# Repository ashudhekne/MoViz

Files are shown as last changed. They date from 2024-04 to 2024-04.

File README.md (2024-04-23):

# MoViz
Motion visualization using UWB and IMU

#HardwareFiles
If you want to manufacture your own UWB+IMU+SDCard+Cortex M0 devices, you can start from the harware files.
This is the hardware we used for our experiments. 

#FirmwareFiles
These files are loaded on the hardware. They are Arduino based.

#VisualizationFiles
These files contain the Processing.org files

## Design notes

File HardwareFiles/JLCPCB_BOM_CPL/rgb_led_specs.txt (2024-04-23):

First Ring design:
WS2812B-MINI-X1
C4154873

Previous UWB Watch system:
XINGLIGHT XL-3535RGBC-WS2812B

C2843786

Current BOM:
XINGLIGHT XL-3535RGBC-WS2812B
C2843786

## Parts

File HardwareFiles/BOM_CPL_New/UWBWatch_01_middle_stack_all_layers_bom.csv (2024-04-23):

Comment | Designator | Footprint | LCSC Part #
microsd | X4 | MICROSD | C2889263

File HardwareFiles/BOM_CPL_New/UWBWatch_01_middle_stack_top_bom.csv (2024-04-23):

Comment | Designator | Footprint | LCSC Part #
microsd | X4 | MICROSD

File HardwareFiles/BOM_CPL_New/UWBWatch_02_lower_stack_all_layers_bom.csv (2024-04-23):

Comment | Designator | Footprint | LCSC Part #
0.1uF | C3 C16 C17 C19 | 0402
1.0uF | C18 | 0603
1K | R6 | 0603-NO
2.2K | R9 | 0603-NO
4.7k | R1 | 0603
10k | R13 | 0603
10uF | C2 C11 C15 | 0805-NO
10µF | C10 | 0805-NO
100k | R4 | 0603-NO
10103594-0001LF | J1 | AMPHENOL_10103594-0001LF
B3U-3000P | S1 | SW_B3U-3000P
MBR120 | D4 | SOD-123
MCP73831T-2ACI/OT | U3 | SOT23-5
RED | L | CHIPLED_0805_NOOUTLINE
SPX3819-3.3 | U2 | SOT23-5
WS2812B3535 | LED1 | LED3535
0.1uF | C1 C4 | 0402
1uF | C5 C9 C14 | 0603-NO
4.7k | R2 | 0603
10K\ | R8 | 0603-NO
10uF | C13 | 0805-NO
10µF | C8 C12 | 0805-NO
22pF | C6 C7 | 0603-NO
32.768 | X2 | XTAL3215
100K | R5 | 0603-NO
100k | R3 | 0603-NO
ATSAMD21G18_QFN | U$4 | TQFN48_7MM
LIS2MDL | IC1 | LGA12_2X2MM
LSM6DS0 | U1 | LGA14L

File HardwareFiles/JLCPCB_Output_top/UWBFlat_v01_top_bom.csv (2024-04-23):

Comment | Designator | Footprint | LCSC Part #
0.1uF | C3 C16 C17 C19 | 0402
1.0uF | C18 | 0603
1K | R6 | 0603-NO
2.2K | R9 | 0603-NO
4.7k | R1 | 0603
10k | R13 | 0603
10uF | C2 C11 C15 | 0805-NO
10µF | C10 | 0805-NO
22uF | C20 C21 C22 | 0805
100k | R4 | 0603-NO
100k | R7 | 0603
10103594-0001LF | J1 | AMPHENOL_10103594-0001LF
B3U-3000P | S1 | SW_B3U-3000P
DWM1000 | U$1 | DWM1000
MBR120 | D4 | SOD-123
MCP73831T-2ACI/OT | U3 | SOT23-5
RED | L | CHIPLED_0805_NOOUTLINE
SPX3819-3.3 | U2 | SOT23-5
WS2812B3535 | LED1 | LED3535

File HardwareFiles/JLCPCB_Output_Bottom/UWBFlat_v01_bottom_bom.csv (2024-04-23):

Comment | Designator | Footprint | LCSC Part #
0.1uF | C1 C4 | 0402
1uF | C5 C9 C14 | 0603-NO
4.7k | R2 | 0603
10K\ | R8 | 0603-NO
10uF | C13 | 0805-NO
10µF | C8 C12 | 0805-NO
22pF | C6 C7 | 0603-NO
32.768 | X2 | XTAL3215
100K | R5 | 0603-NO
100k | R3 | 0603-NO
10103594-0001LF | J1 | AMPHENOL_10103594-0001LF
ATSAMD21G18_QFN | U$4 | TQFN48_7MM
LIS2MDL | IC1 | LGA12_2X2MM
LSM6DS0 | U1 | LGA14L
microsd | X4 | MICROSD

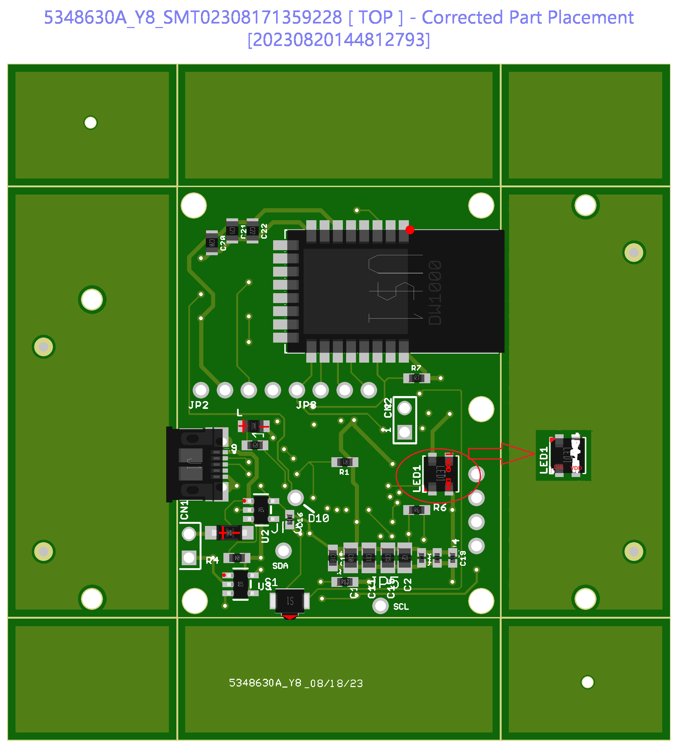
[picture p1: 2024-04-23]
HardwareFiles/JLCPCB_BOM_CPL/Produce_DanZhi.SMT_Snapshot.Top.5348630A_Y8.SMT02308171359228_corrected.png

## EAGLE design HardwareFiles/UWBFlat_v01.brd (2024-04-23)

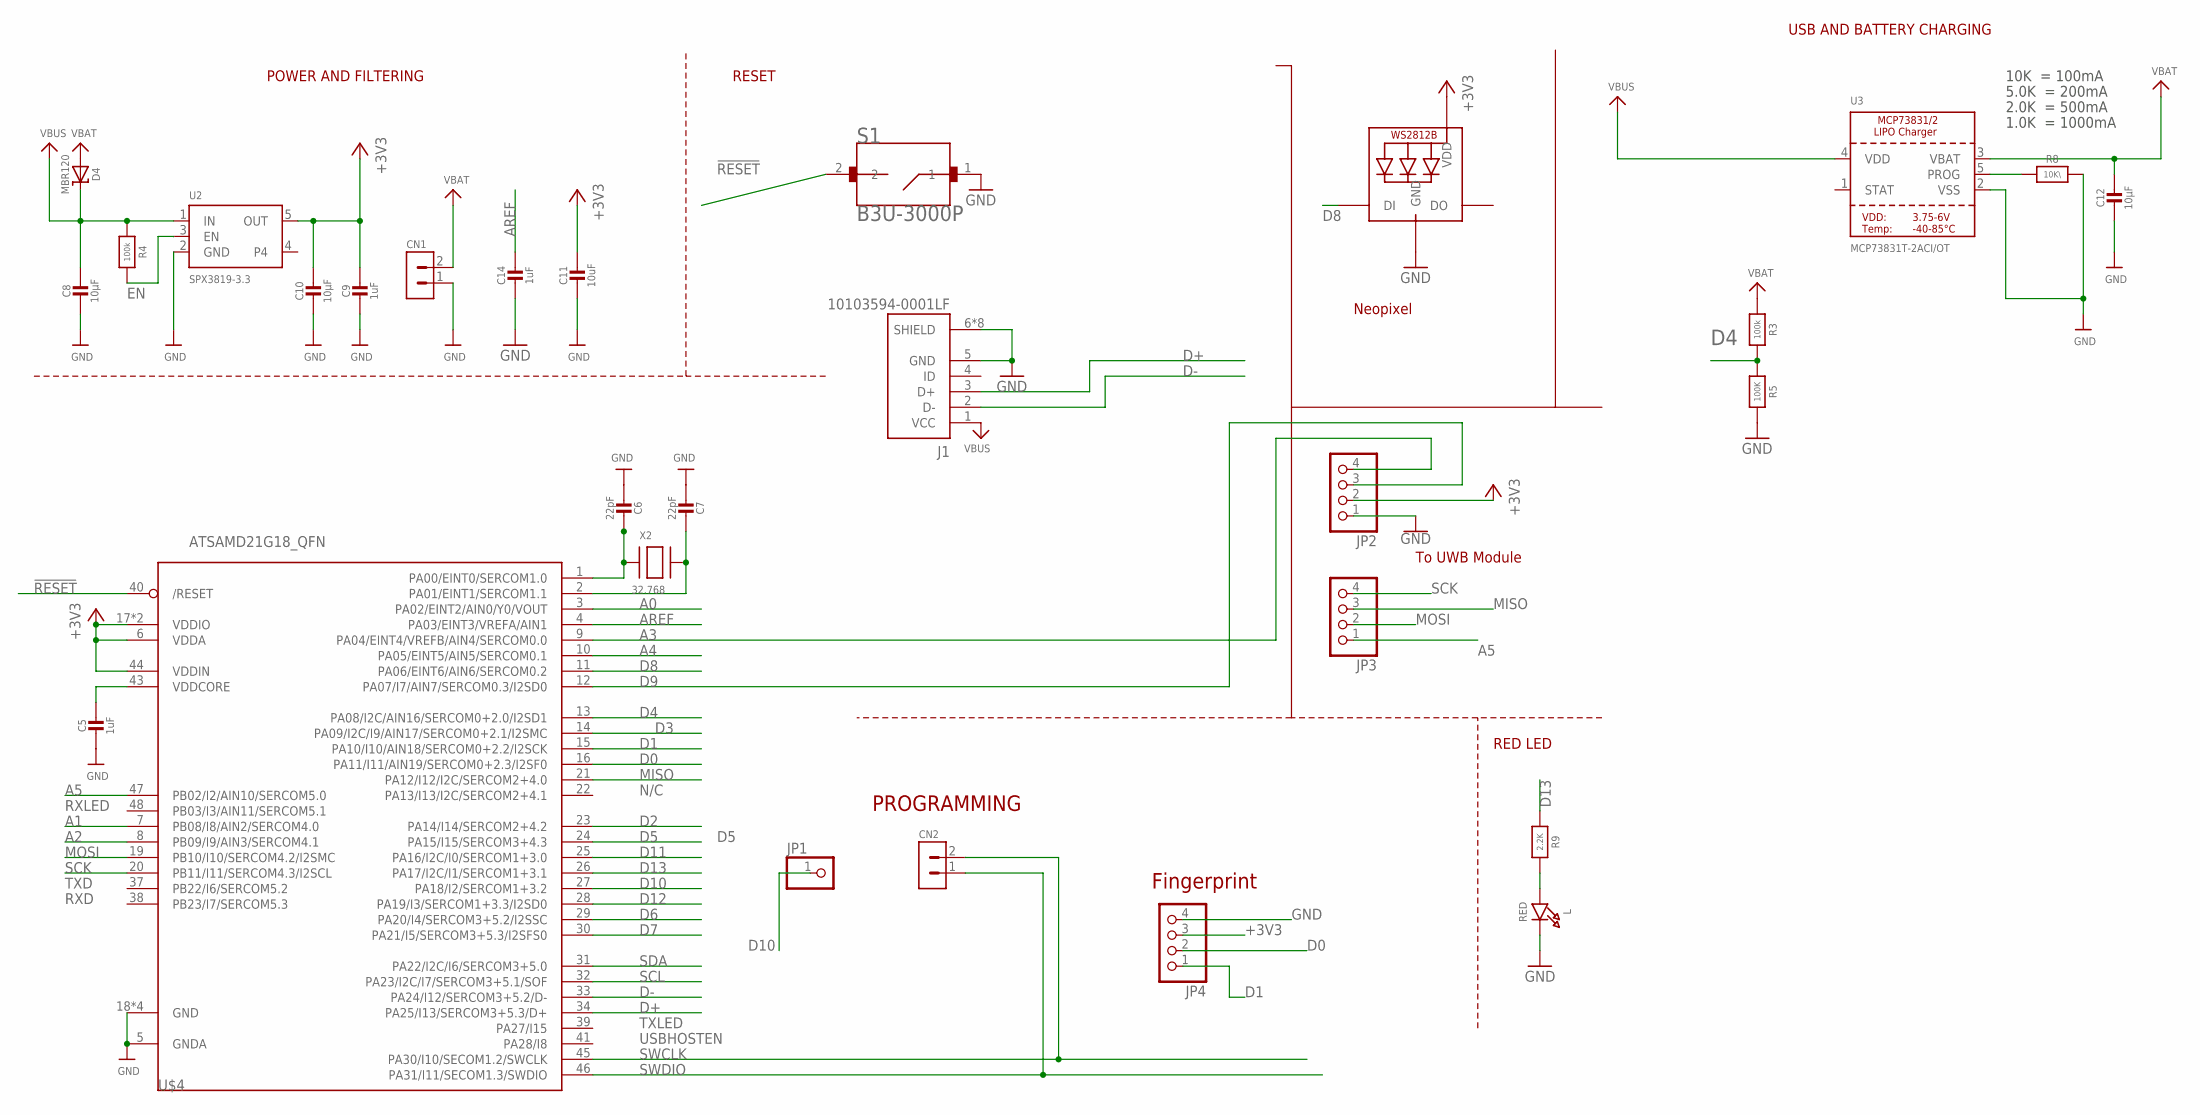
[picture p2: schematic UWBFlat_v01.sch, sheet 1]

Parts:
C5, C9, C14: 1uF; 0603-NO
C6, C7: 22pF; 0603-NO
C8, C10, C12: 10µF; 0805-NO
C11: 10uF; 0805-NO
CN1, CN2: HEADER_1X02
D4: MBR120; SOD-123
J1: 10103594-0001LF; AMPHENOL_10103594-0001LF
JP1: PINHD-1X1CB; 1X01-CLEANBIG
JP2, JP3, JP4: HEADER-1X4ROUND; 1X04_ROUND
L: RED; CHIPLED_0805_NOOUTLINE
LED1: WS2812B3535; LED3535
R3, R4: 100k; 0603-NO
R5: 100K; 0603-NO
R8: 10K\; 0603-NO
R9: 2.2K; 0603-NO
S1: B3U-3000P; SW_B3U-3000P
U2: SPX3819-3.3; SOT23-5
U3: MCP73831T-2ACI/OT; SOT23-5
U$4: ATSAMD21G18_QFN; TQFN48_7MM
X2: 32.768; XTAL3215

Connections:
!RESET: S1.2, U$4.40 (/RESET)
+3V3: C9.1, C10.1, C11.1, JP2.2, JP4.3, LED1.2 (VDD), U2.5 (OUT), U$4.6 (VDDA), U$4.17 (VDDIO), U$4.36 (VDDIO), U$4.44 (VDDIN); also elsewhere on the board
A0: U$4.3 (PA02/EINT2/AIN0/Y0/VOUT)
A1: U$4.7 (PB08/I8/AIN2/SERCOM4.0)
A2: U$4.8 (PB09/I9/AIN3/SERCOM4.1)
A3: JP2.4, U$4.9 (PA04/EINT4/VREFB/AIN4/SERCOM0.0); also elsewhere on the board
A4: U$4.10 (PA05/EINT5/AIN5/SERCOM0.1)
A5: JP3.1, U$4.47 (PB02/I2/AIN10/SERCOM5.0); also elsewhere on the board
AREF: C14.1, U$4.4 (PA03/EINT3/VREFA/AIN1)
D0: JP4.2, U$4.16 (PA11/I11/AIN19/SERCOM0+2.3/I2SF0)
D1: JP4.1, U$4.15 (PA10/I10/AIN18/SERCOM0+2.2/I2SCK)
D2: U$4.23 (PA14/I14/SERCOM2+4.2)
D3: U$4.14 (PA09/I2C/I9/AIN17/SERCOM0+2.1/I2SMC)
D4: R3.2, R5.1, U$4.13 (PA08/I2C/AIN16/SERCOM0+2.0/I2SD1)
D5: U$4.24 (PA15/I15/SERCOM3+4.3)
D6: U$4.29 (PA20/I4/SERCOM3+5.2/I2SSC)
D7: U$4.30 (PA21/I5/SERCOM3+5.3/I2SFS0)
D8: LED1.1 (DI), U$4.11 (PA06/EINT6/AIN6/SERCOM0.2)
D9: JP2.3, U$4.12 (PA07/I7/AIN7/SERCOM0.3/I2SD0); also elsewhere on the board
D10: JP1.1, U$4.27 (PA18/I2/SERCOM1+3.2); also elsewhere on the board
D11: U$4.25 (PA16/I2C/I0/SERCOM1+3.0)
D12: U$4.28 (PA19/I3/SERCOM1+3.3/I2SD0)
D13: R9.1, U$4.26 (PA17/I2C/I1/SERCOM1+3.1)
D+: J1.3 (D+), U$4.34 (PA25/I13/SERCOM3+5.3/D+)
D-: J1.2 (D-), U$4.33 (PA24/I12/SERCOM3+5.2/D-)
EN: R4.2, U2.3 (EN)
GND: C5.2, C6.2, C7.2, C8.2, C9.2, C10.2, C11.2, C12.2, C14.2, CN1.1, J1.5 (GND), J1.6 (SHIELD), J1.7 (SHIELD), J1.8 (SHIELD), J1.9 (SHIELD), J1.10 (SHIELD), J1.11 (SHIELD), J1.S1 (SHIELD), J1.S2 (SHIELD), JP2.1, JP4.4, L.C, LED1.4 (GND), R5.2, R8.2, S1.1, U2.2 (GND), U3.2 (VSS), U$4.5 (GNDA), U$4.18 (GND), U$4.35 (GND), U$4.42 (GND), U$4.THERMAL (GND); also elsewhere on the board
MISO: JP3.3, U$4.21 (PA12/I12/I2C/SERCOM2+4.0); also elsewhere on the board
MOSI: JP3.2, U$4.19 (PB10/I10/SERCOM4.2/I2SMC); also elsewhere on the board
unnamed: R8.1, U3.5 (PROG)
unnamed: C6.1, U$4.1 (PA00/EINT0/SERCOM1.0), X2.P$1
unnamed: C7.1, U$4.2 (PA01/EINT1/SERCOM1.1), X2.P$2
unnamed: L.A, R9.2
SCK: JP3.4, U$4.20 (PB11/I11/SERCOM4.3/I2SCL); also elsewhere on the board
SCL: U$4.32 (PA23/I2C/I7/SERCOM3+5.1/SOF); also elsewhere on the board
SDA: U$4.31 (PA22/I2C/I6/SERCOM3+5.0); also elsewhere on the board
SWCLK: CN2.2, U$4.45 (PA30/I10/SECOM1.2/SWCLK)
SWDIO: CN2.1, U$4.46 (PA31/I11/SECOM1.3/SWDIO)
VBAT: C12.1, CN1.2, D4.A, R3.1, U3.3 (VBAT)
VBUS: C8.1, D4.C, J1.1 (VCC), R4.1, U2.1 (IN), U3.4 (VDD)
VDDCORE1: C5.1, U$4.43 (VDDCORE)

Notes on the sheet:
N/C
TXLED
USBHOSTEN
RXLED
TXD
RXD
POWER AND FILTERING
RESET
RED LED
PROGRAMMING
To UWB Module
Neopixel
10K = 100mA
5.0K = 200mA
2.0K = 500mA
1.0K = 1000mA
USB AND BATTERY CHARGING
Fingerprint

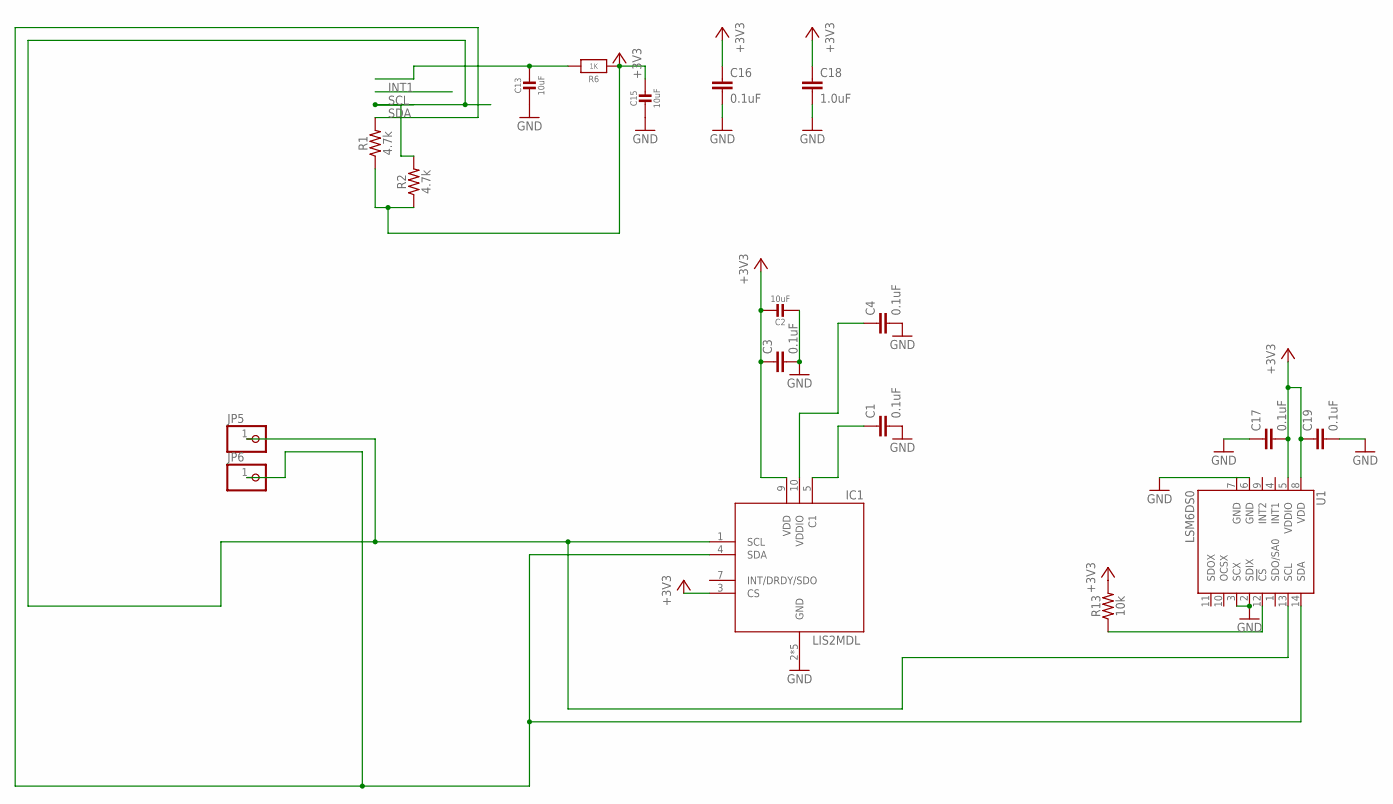
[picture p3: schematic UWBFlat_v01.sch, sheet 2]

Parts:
C1, C3, C4, C16, C17, C19: 0.1uF; 0402
C2, C13, C15: 10uF; 0805-NO
C18: 1.0uF; 0603
IC1: LIS2MDL; LGA12_2X2MM
JP5, JP6: PINHD-1X1CB; 1X01-CLEANBIG
R1, R2: 4.7k; 0603
R6: 1K; 0603-NO
R13: 10k; 0603
U1: LSM6DS0; LGA14L

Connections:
+3V3: C2.1, C3.1, C15.1, C16.1, C17.2, C18.1, C19.1, IC1.3 (CS), IC1.9 (VDD), R1.1, R2.1, R6.1, R13.2, U1.5 (VDDIO), U1.8 (VDD); also elsewhere on the board
GND: C1.2, C2.2, C3.2, C4.2, C13.2, C15.2, C16.2, C17.1, C18.2, C19.2, IC1.2 (GND), IC1.6 (GND), IC1.8 (GND), IC1.11 (GND), IC1.12 (GND), U1.2 (SDIX), U1.3 (SCX), U1.6 (GND), U1.7 (GND); also elsewhere on the board
unnamed: C13.1, R6.2
unnamed: C1.1, IC1.5 (C1)
unnamed: C4.1, IC1.10 (VDDIO)
unnamed: R13.1, U1.12 (!CS!)
SCL: IC1.1 (SCL), JP5.1, R2.2, U1.13 (SCL); also elsewhere on the board
SDA: IC1.4 (SDA), JP6.1, R1.2, U1.14 (SDA); also elsewhere on the board

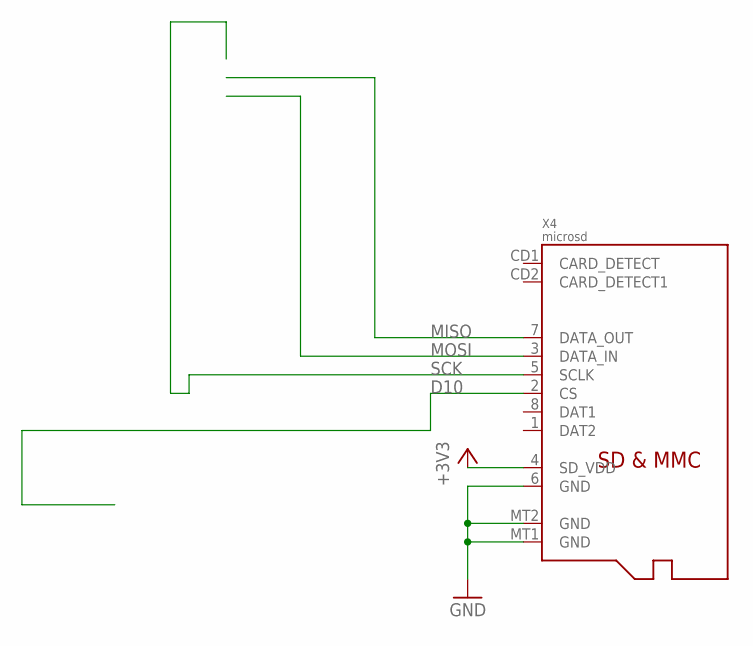
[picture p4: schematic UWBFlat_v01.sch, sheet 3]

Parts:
X4: microsd; MICROSD

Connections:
+3V3: X4.4 (SD_VDD); also elsewhere on the board
D10: X4.2 (CS); also elsewhere on the board
GND: X4.6 (GND), X4.MT1 (GND), X4.MT2 (GND); also elsewhere on the board
MISO: X4.7 (DATA_OUT); also elsewhere on the board
MOSI: X4.3 (DATA_IN); also elsewhere on the board
SCK: X4.5 (SCLK); also elsewhere on the board

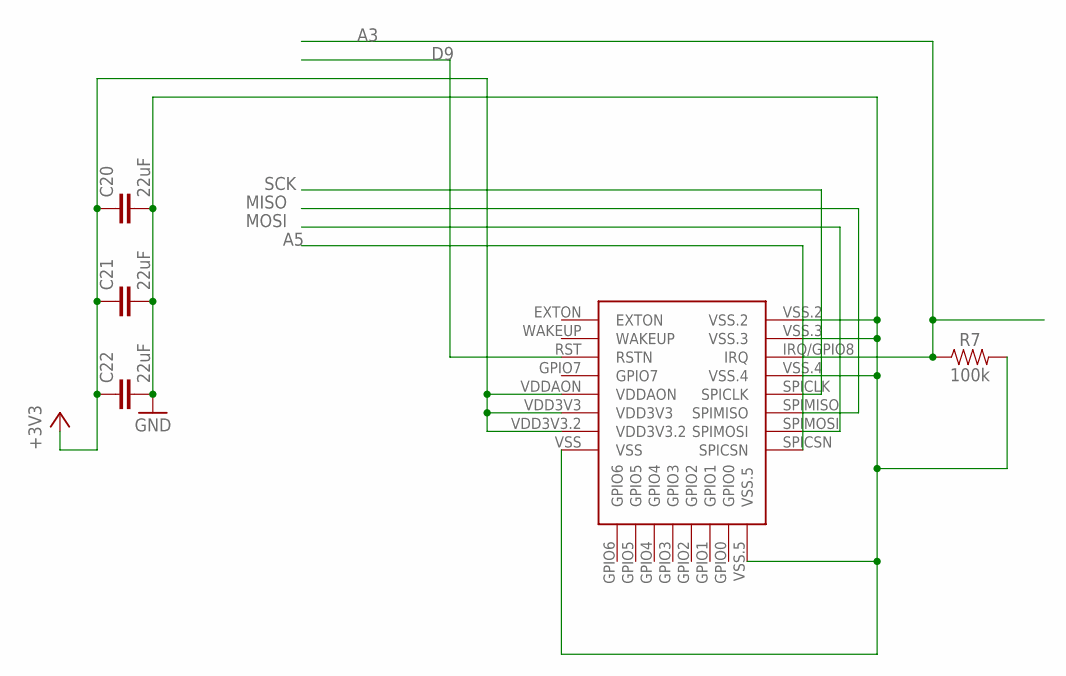
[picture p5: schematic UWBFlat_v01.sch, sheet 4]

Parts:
C20, C21, C22: 22uF; 0805
R7: 100k; 0603
U$1: DWM1000

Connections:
+3V3: C20.1, C21.1, C22.1, U$1.VDD3V3, U$1.VDD3V3.2, U$1.VDDAON; also elsewhere on the board
A3: R7.1, U$1.IRQ/GPIO8 (IRQ); also elsewhere on the board
A5: U$1.SPICSN; also elsewhere on the board
D9: U$1.RST (RSTN); also elsewhere on the board
GND: C20.2, C21.2, C22.2, R7.2, U$1.VSS, U$1.VSS.2, U$1.VSS.3, U$1.VSS.4, U$1.VSS.5; also elsewhere on the board
MISO: U$1.SPIMISO; also elsewhere on the board
MOSI: U$1.SPIMOSI; also elsewhere on the board
SCK: U$1.SPICLK; also elsewhere on the board

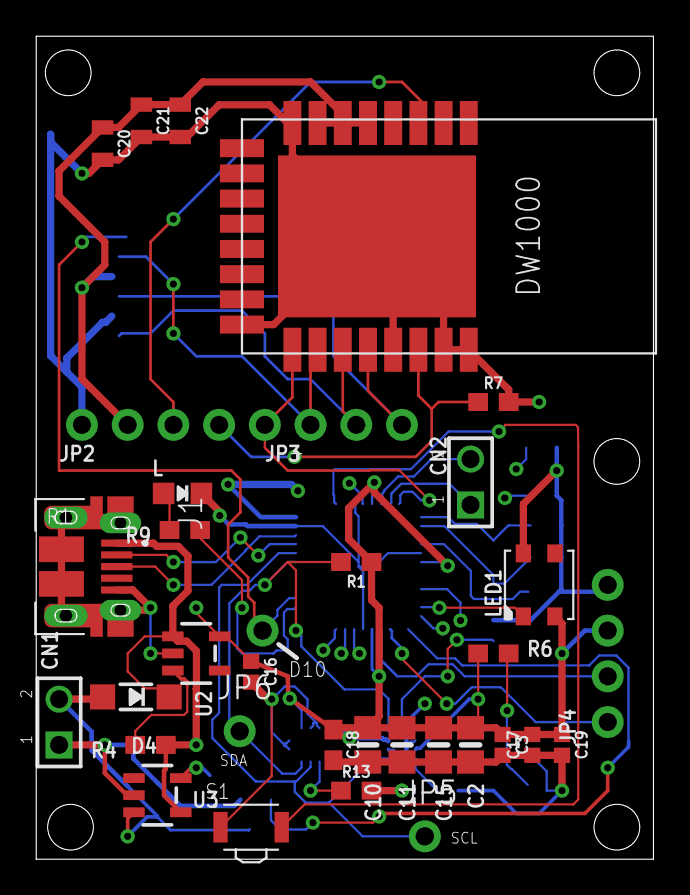
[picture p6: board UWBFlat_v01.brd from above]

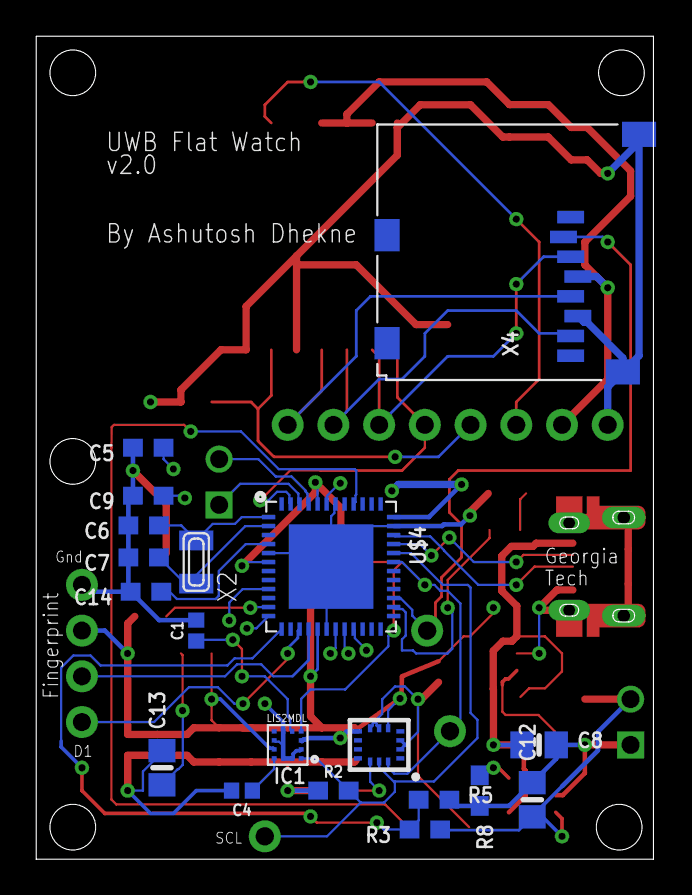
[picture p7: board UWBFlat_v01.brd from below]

Board: 4 copper layers, 34.3 x 45.7 mm, 53 parts (19 on the bottom side), 34 nets.

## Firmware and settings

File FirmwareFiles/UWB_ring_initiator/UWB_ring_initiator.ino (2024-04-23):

/*
 * Copyright (c) 2021 by Yifeng Cao <ycao361@gatech.edu>
 * Peer-peer protocol
 *
 * Licensed under the Apache License, Version 2.0 (the "License");
 * you may not use this file except in compliance with the License.
 * You may obtain a copy of the License at
 *
 *     http://www.apache.org/licenses/LICENSE-2.0
 *
 * Unless required by applicable law or agreed to in writing, software
 * distributed under the License is distributed on an "AS IS" BASIS,
 * WITHOUT WARRANTIES OR CONDITIONS OF ANY KIND, either express or implied.
 * See the License for the specific language governing permissions and
 * limitations under the License.
 *
 * @file DWM1000-TWR.ino
 * 
 *  
 */

#include <SPI.h>
#include <math.h>
#include <DW1000.h>
#include <DW1000Constants.h>
#include "ringActionFunctions.h"
#include "genericFunctions.h"
#include "RangingContainer.h"
#include "Adafruit_LSM9DS1.h"
#include <SdFat.h>
#include <time.h>
#include<TimeLib.h>
#include<Wire.h>
// #include <Adafruit_ISM330DHCX.h>
// #include <Adafruit_LIS3MDL.h>
#include <LSM6DSOSensor.h>

TwoWire dev_i2c(&sercom3, SDA, SCL);  
LSM6DSOSensor AccGyr(&dev_i2c);

// Adafruit_LIS3MDL lis3mdl;
// Adafruit_ISM330DHCX ism330dhcx;

// PIN Macro
#define VBATPIN A2
#define LED_PIN 12
#define NOISE_PIN 13
#define GOOD_PIN 6
#define SILENCE_PIN 5
#define DEV_INDICATOR_PIN 13

//Timer for implementing timeouts
#define CPU_HZ 48000000
#define TIMER_PRESCALER_DIV 1024

//Other Macros
#define USB_CONNECTION 0
#define DEBUG_PRINT 0


#if(OUR_UWB_FEATHER==1)
const uint8_t PIN_RST = 9; // reset pin
const uint8_t PIN_IRQ = 17; // irq pin
const uint8_t PIN_SS = 19; // spi select pin
#endif

#if(AUS_UWB_FEATHER==1)
const uint8_t PIN_RST = 2; // reset pin
const uint8_t PIN_IRQ = 3; // irq pin
const uint8_t PIN_SS = 4; // spi select pin
#endif



// Global control variables
volatile boolean received = false;
volatile boolean error = false;
volatile int16_t numReceived = 0; // todo check int type
volatile boolean sendComplete = false;
volatile boolean RxTimeout = false;

byte beacon_msg[BEACON_MSG_LEN] = {0};
int dst_index = 2;
uint16_t current_seq = 0;
uint64_t prev_my_send_time[257] = {0};
uint64_t prev_my_recv_time[257] = {0};
uint64_t prev_other_send_time[257] = {0};
uint64_t prev_other_recv_time[257] = {0};
uint16_t prev_send_seq[257] = {0};
uint16_t prev_recv_seq[257] = {0};
int imu_start_idx = 0;

volatile uint8_t current_state = STATE_IDLE;
unsigned long silenced_at = 0;
long randNumber;
int currentSlots = 8;


STATES states;


// SD-card related variables
SdFat sd;
SdFile store_distance; //The root file system useful for deleting all files on the SDCard
char filename[14];
int filenum = 0;
int entries_in_file=0;
int SDChipSelect = 10;
int SDEnabled=0;


byte rx_buffer[1024];
// uint8_t myAcc[1000];
int32_t imu_buffer[IMU_BUFFER_SIZE][7] = {0};
int n_imu_samples = 0;

Ranging thisRange;

double currentTime;
double elapsedTime;

double globalTimeMs = 0;
double lastTimeMs = 0;
double currentTimeMs = 0;
boolean timerStart = false;
boolean start_new_receiver = 1;

//Time
boolean first_start = true;
double elapsed_time_us = 0;
double start_time_us = 0;
double send_info_start_time_us = 0;
double send_info_elapsed_time_us = 0;
int send_info_first_start = 1;
double global_time_us = 0;
double prev_imu_time_us = 0;
double elapsed_imu_time_us = 0;
int start_pattern_recognition = 1;
int n_cir_verifier = 0;

uint8_t raw_acc_mem[4063] = {0};
// uint8_t raw_acc_mem_verify[3][4063];
int cir_left_part = 10;
int cir_right_part = 50; // [a - cir_left, a+cir_right-1]
uint16_t rx_timeout_us = 0;
// uint16_t all_imu_data[2000][6];

void imu_setup();
void startTimer(int frequencyHz);
void setTimerFrequency(int frequencyHz);
void TC3_Handler();

typedef struct DeviceRespTs {
  int deviceID;
  uint64_t respRxTime;
};


void receiver(uint16_t rxtoval=0 ) {
  RxTimeout = false;
  received = false;
  DW1000.newReceive();
  set_customized_configs2();
  // we cannot don't need to restart the receiver manually
  DW1000.receivePermanently(false);
  DW1000.setRxTimeout(rxtoval);
  DW1000.startReceive();
}


void setup() {
  pinMode(LED_PIN, OUTPUT);
  pinMode(NOISE_PIN, OUTPUT);
  pinMode(GOOD_PIN, OUTPUT);
  pinMode(DEV_INDICATOR_PIN, OUTPUT);
  pinMode(SILENCE_PIN, INPUT_PULLUP);
  digitalWrite(GOOD_PIN, HIGH);
  analogReadResolution(10);
  // DEBUG monitoring
  Serial.begin(115200);
  while(!Serial)
  {
    delay(10);
    #if(USB_CONNECTION==0)
      break;
    #endif
  }
imu_setup();
Serial.print("Waiting...");
delay(5000);
Serial.print("Should see this...");



  randomSeed(analogRead(0));
  Serial.println(F("Peer-peer ranging protocol"));
  Serial.println("Free memory: ");
  Serial.println(freeMemory());
  // initialize the driver
  DW1000.begin(PIN_IRQ, PIN_RST);
  DW1000.select(PIN_SS);
  
  Serial.println(F("DW1000 initialized ..."));
  // general configuration
  DW1000.newConfiguration();
  DW1000.setDefaults();
  set_customized_configs2();
  DW1000.setDeviceAddress(6);
  DW1000.setNetworkId(10);
  // DW1000.enableMode(DW1000.MODE_UMPIRE_TRACKING);
  DW1000.commitConfiguration();
  Serial.println(F("Committed configuration ..."));
  // DEBUG chip info and registers pretty printed
  char msg[128];
  DW1000.getPrintableDeviceIdentifier(msg);
  Serial.print("Device ID: "); Serial.println(msg);
  DW1000.getPrintableExtendedUniqueIdentifier(msg);
  Serial.print("Unique ID: "); Serial.println(msg);
  DW1000.getPrintableNetworkIdAndShortAddress(msg);
  Serial.print("Network ID & Device Address: "); Serial.println(msg);
  DW1000.getPrintableDeviceMode(msg);
  Serial.println(msg);
  Serial.print("Device mode: ");
  Serial.println(DW1000._deviceMode);
  uint8_t pac_size = DW1000._pacSize;
  Serial.print("Pac size: "); Serial.println(pac_size);
  uint8_t use_extended = DW1000._extendedFrameLength;
  Serial.print("Use extended frame: ");
  if (use_extended == 0x3){
    Serial.println(1);
  } else if (use_extended == 0){
    Serial.println(0);
  } else {
    Serial.println("?");
  }
  byte sfd_length[1];
  DW1000.readBytes(USR_SFD, 0, sfd_length, 1);
  Serial.print("SFD length: ");
  Serial.println(sfd_length[0]);
  byte channel_control[4];
  DW1000.readBytes(CHAN_CTRL, 0, channel_control, 4);
  Serial.print("Channel control: ");
  Serial.print(channel_control[0]);
  Serial.print(",");
  Serial.print(channel_control[1]);
  Serial.print(",");
  Serial.print(channel_control[2]);
  Serial.print(",");
  Serial.print(channel_control[3]);
  Serial.println("");

  byte tx_frame_ctrl[4];
  DW1000.readBytes(TX_FCTRL, 0, tx_frame_ctrl, 4);
  Serial.print("tx frame ctrl: ");
  Serial.print(tx_frame_ctrl[0]);
  Serial.print(",");
  Serial.print(tx_frame_ctrl[1]);
  Serial.print(",");
  Serial.print(tx_frame_ctrl[2]);
  Serial.print(",");
  Serial.print(tx_frame_ctrl[3]);
  Serial.println("");

  // byte sys_config[4];
  // DW1000.readBytes(SYS_CFG, 0, sys_config, LEN_SYS_CFG);
  // Serial.print("sys_config: ");
  // Serial.print(sys_config[0]);
  // Serial.print(",");
  // Serial.print(sys_config[1]);
  // Serial.print(",");
  // Serial.print(sys_config[2]);
  // Serial.print(",");
  // Serial.print(sys_config[3]);
  // Serial.println("");


  // attach callback for (successfully) received messages
  DW1000.attachReceivedHandler(handleReceived);
  DW1000.attachReceiveTimeoutHandler(handleRxTO);
  DW1000.attachReceiveFailedHandler(handleError);
  DW1000.attachErrorHandler(handleError);
  DW1000.attachSentHandler(handleSent);
  // start reception
  
  current_state = STATE_IDLE;

#if (INITIATOR == 1)
digitalWrite(DEV_INDICATOR_PIN, 1);
delay(500);
digitalWrite(DEV_INDICATOR_PIN, 0);
delay(500);
digitalWrite(DEV_INDICATOR_PIN, 1);
delay(500);
digitalWrite(DEV_INDICATOR_PIN, 0);
delay(500);
digitalWrite(DEV_INDICATOR_PIN, 1);
delay(5000);
digitalWrite(DEV_INDICATOR_PIN, 0);
//delay(500);
#else
digitalWrite(DEV_INDICATOR_PIN, 1);
delay(1000);
digitalWrite(DEV_INDICATOR_PIN, 0);
delay(500);
digitalWrite(DEV_INDICATOR_PIN, 1);
delay(200);
digitalWrite(DEV_INDICATOR_PIN, 0);
delay(500);
digitalWrite(DEV_INDICATOR_PIN, 1);
delay(500);
digitalWrite(DEV_INDICATOR_PIN, 0);
#endif
  // startTimer(80);
}


void handleSent() {
  // status change on sent success
  sendComplete = true;
  //Serial.println("Send complete");
}


void handleReceived() {
  // status change on reception success
  
  DW1000.getData(rx_buffer, DW1000.getDataLength());
  //Serial.println("Received something...");
  received = true;
  //show_packet(rx_buffer, DW1000.getDataLength());
}

void handleError() {
  Serial.println("Error!!!");
  error = true;
}

void handleRxTO() {
  RxTimeout = true;
  #if (DEBUG_PRINT==1)
  Serial.println("Rx Timeout");
  Serial.println("State: ");
  Serial.println(current_state);
  #endif
}



void test_tx_logic(){
  elapsed_time_us = get_elapsed_time_us(start_time_us);
  if (elapsed_time_us > 1e6) {
    current_seq = increment_seq(current_seq);
    Serial.print("Send a message: ");
    Serial.println(current_seq);
    send_beacon(1, current_seq, 0);
    start_time_us = get_time_us();
  }
  return;
}

void test_rx_logic(){
	if (first_start) {
    receiver(0);
    first_start = false;
    Serial.println("Start receiver!");
  }
  if (received) {
    uint16_t seq = rx_buffer[SEQ_IDX] + ((rx_buffer[SEQ_IDX+1]) << 8);
    Serial.print("Receive a message: ");
    Serial.println(seq);
    received = false;
    receiver(0);
  }
  if (RxTimeout) {
    Serial.println("Rx Timeout!");
  }
}

void two_way_ranging_logic() {
  if(start_new_receiver){
    receiver(0);
  }
  start_new_receiver = 0;
  
  // Add one IMU data to buffer.
  elapsed_imu_time_us = get_elapsed_time_us(prev_imu_time_us);
   if (elapsed_imu_time_us > 1e6 / imu_rate) {
    
     //add_imu_to_buffer(imu_buffer, n_imu_samples,MAX_IMU_SAMPLES_IN_BUFFER_TWRCIR);
     // Serial.print("n_imu_samples=");
     // Serial.println(n_imu_samples);
     prev_imu_time_us = get_time_us();
   }

  // UWB logic
  switch(current_state) {
    case STATE_IDLE: {
        //when every node initially starts, it has to wait a full loop in RECV state otherwise it will interrupt on-going ranging
        current_state = STATE_SEND;//STATE_RECEIVE;
        start_time_us = get_time_us();
        start_new_receiver = 1;
        break;
    }
    case STATE_RECEIVE:
			{
				elapsed_time_us = get_elapsed_time_us(start_time_us);
				if (elapsed_time_us > response_expect_timeout_us && received == 0) {
					current_state = STATE_SEND;
          start_time_us = get_time_us();
					start_new_receiver = 0; // If the old receiver expires, start a new receiver. (The ring should avoid actively sending)
					break;
				} else {
					if (received == 1){
            Serial.println("Received a packet");
						receive_beacon();
            start_new_receiver = 0;
            current_state = STATE_SEND;
					} else {
            start_new_receiver = 0;
            //Serial.println("Continue to listen...");
						break;
					}
				}
				break;
			}
    case STATE_SEND:
    {
      Serial.println("Send a packet");
      current_seq = increment_seq(current_seq);
      initiator_send_beacon(dst_index, current_seq, prev_recv_seq[dst_index]);
      start_time_us = get_time_us();
      current_state = STATE_RECEIVE;
      start_new_receiver = 1;
      Serial.println("Send complete");
      break;
    }
  }
}

void ring_logic_1_0(){
  if(start_new_receiver){
    receiver(rx_timeout_us);
  }
  start_new_receiver = 0;
  
  // Add one IMU data to buffer.
  elapsed_imu_time_us = get_elapsed_time_us(prev_imu_time_us);
  // if (elapsed_imu_time_us > 1e6 / imu_rate) {
    
    // add_imu_to_buffer(imu_buffer, n_imu_samples);
    // Serial.print("n_imu_samples=");
    // Serial.println(n_imu_samples);
    // prev_imu_time_us = get_time_us();
  // }

  // UWB logic
  switch(current_state) {
    case STATE_IDLE: 
    {
        //when every node initially starts, it has to wait a full loop in RECV state otherwise it will interrupt on-going ranging
        current_state = STATE_HS_REQUEST_EXPECTED;
        // rx_timeout_us = deca_timeout_us;
        rx_timeout_us = 0;
        start_time_us = get_time_us();
        start_new_receiver = 1;
        start_pattern_recognition = 0;
        n_imu_samples = 0;
        n_cir_verifier = 0;
        prev_imu_time_us = 0;
        imu_start_idx = 0;
        send_info_first_start = 1;
        break;
    }
    case STATE_HS_REQUEST_EXPECTED: 
    {
				if (received == 0){
          break;
        }
        received = 0;
        int status = receive_hs_request();
        if (status == 0) {
          start_new_receiver = 0;
          current_state = STATE_HS_SEND_REPLY;
        } else {
          start_new_receiver = 1;
          break;
        }
				break;
		}
    case STATE_HS_SEND_REPLY:
    {
      Serial.println("Send a reply packet");
      current_seq = increment_seq(current_seq);
      send_hs_reply(dst_index, current_seq, prev_recv_seq[dst_index]);
      start_time_us = get_time_us();
      current_state = STATE_HS_PCACK_EXPECTED;
      start_new_receiver = 1;
      rx_timeout_us = 0;
      break;
    }
    case STATE_HS_PCACK_EXPECTED:
    {
      elapsed_time_us = get_elapsed_time_us(start_time_us);
      if (elapsed_time_us > ONE_SECOND_TIMEOUT_US) {
        current_state = STATE_IDLE;
        start_time_us = get_time_us();
        rx_timeout_us = 0;
        start_new_receiver = 1; // If the old receiver expires, start a new receiver. (The ring should avoid actively sending)
        break;
      } 
      if (received == 0){
        start_new_receiver = 0;
        break;
      }
      received = 0;
      Serial.println("Receive something in STATE_HS_PCACK_EXPECTED");
      int status = receive_hs_pcack();
      if (status == 0) {
        current_state = STATE_HS_SEND_RINGACK;
        start_time_us = get_time_us();
        start_new_receiver = 0;
        Serial.println("Handshaking is successful. Wait for two way ranging.");
      } else {
        start_new_receiver = 1;
        break;
      }
      break;
    }
    case STATE_HS_SEND_RINGACK: {
      Serial.println("Send ROMG ACK, go to STATE_TWR_RECEIVE");
      current_seq = increment_seq(current_seq);
      send_hs_ringack(dst_index, current_seq, prev_recv_seq[dst_index]);
      start_time_us = get_time_us();
      current_state = STATE_TWR_RECEIVE;
      start_new_receiver = 1;
      rx_timeout_us = 0;
      break;
    }
    case STATE_TWR_RECEIVE: {
      elapsed_time_us = get_elapsed_time_us(start_time_us);
      if (elapsed_time_us > FIVE_SECOND_TIMEOUT_US) {
        current_state = STATE_IDLE;
        start_time_us = get_time_us();
        rx_timeout_us = 0;
        start_new_receiver = 1; 
        Serial.println("TWR receive timeout");
        break;
      } 
      if (received == 0){
        start_new_receiver = 0;
        break;
      }
      received = 0;
      int status = receive_twr_beacon();
      if (status == 0) {
        current_state = ((start_pattern_recognition == 1) ? STATE_PAT_SEND_REPLY:
          STATE_TWR_SEND);
        start_time_us = get_time_us();
        start_new_receiver = 0;
      } else {
        start_new_receiver = 1;
        break;
      }
      break;
    }
    case STATE_TWR_SEND: {
      Serial.println("Send a twr short beacon.");
      current_seq = increment_seq(current_seq);
      send_twr_beacon(dst_index, current_seq, prev_recv_seq[dst_index]);
      start_time_us = get_time_us();
      current_state = STATE_TWR_RECEIVE;
      start_new_receiver = 1;
      break;
    }
    case STATE_PAT_SEND_REPLY: {
      current_seq = increment_seq(current_seq);
      send_pat_reply(dst_index, current_seq, prev_recv_seq[dst_index]);
      start_time_us = get_time_us();
      current_state = STATE_PAT_SHORTBEACON_EXPECTED;
      start_new_receiver = 1;
      Serial.println("go to STATE_PAT_SHORTBEACON_EXPECTED");
      break;
    }
    case STATE_PAT_SHORTBEACON_EXPECTED:{
      // Collect IMU data and receive short beacon
      elapsed_imu_time_us = get_elapsed_time_us(prev_imu_time_us);
      if (elapsed_imu_time_us > 1e6 / imu_rate) {
    
        add_imu_to_buffer(imu_buffer, n_imu_samples, MAX_IMU_SAMPLES_IN_BUFFER_APP);
        prev_imu_time_us = get_time_us();
      }
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
void loop() {
  two_way_ranging_logic();
  // ring_logic_1_0();
}





void show_packet(byte packet[], int num) {
  #if (DEBUG_PRINT==1)
  for (int i=0;i<num;i++) {
    Serial.print(packet[i], HEX);
    Serial.print(" ");
  }
  #endif
  
}

//Timer Functions
//Timer functions.
void setTimerFrequency(int frequencyHz) {
  int compareValue = (CPU_HZ / (TIMER_PRESCALER_DIV * frequencyHz)) - 1;
  
  TcCount16* TC = (TcCount16*) TC3;
  // Make sure the count is in a proportional position to where it was
  // to prevent any jitter or disconnect when changing the compare value.
  TC->COUNT.reg = map(TC->COUNT.reg, 0, TC->CC[0].reg, 0, compareValue);
  TC->CC[0].reg = compareValue;
  //Serial.println(TC->COUNT.reg);
  //Serial.println(TC->CC[0].reg);
  while (TC->STATUS.bit.SYNCBUSY == 1);
}

void startTimer(int frequencyHz) {
  
  REG_GCLK_CLKCTRL = (uint16_t) (GCLK_CLKCTRL_CLKEN | GCLK_CLKCTRL_GEN_GCLK0 | GCLK_CLKCTRL_ID_TCC2_TC3) ;
  
  while ( GCLK->STATUS.bit.SYNCBUSY == 1 ); // wait for sync

  TcCount16* TC = (TcCount16*) TC3;
  
  TC->CTRLA.reg &= ~TC_CTRLA_ENABLE;
  while (TC->STATUS.bit.SYNCBUSY == 1); // wait for sync

  // Use the 16-bit timer
  TC->CTRLA.reg |= TC_CTRLA_MODE_COUNT16;
  while (TC->STATUS.bit.SYNCBUSY == 1); // wait for sync

  // Use match mode so that the timer counter resets when the count matches the compare register
  TC->CTRLA.reg |= TC_CTRLA_WAVEGEN_MFRQ;
  while (TC->STATUS.bit.SYNCBUSY == 1); // wait for sync

  // Set prescaler to 1024
  TC->CTRLA.reg |= TC_CTRLA_PRESCALER_DIV1024;
  while (TC->STATUS.bit.SYNCBUSY == 1); // wait for sync

  setTimerFrequency(frequencyHz);

  // Enable the compare interrupt
  TC->INTENSET.reg = 0;
  TC->INTENSET.bit.MC0 = 1;

  
    NVIC_SetPriority(TC3_IRQn, 3);
    NVIC_EnableIRQ(TC3_IRQn);  
    

  TC->CTRLA.reg |= TC_CTRLA_ENABLE;

  while (TC->STATUS.bit.SYNCBUSY == 1); // wait for sync
}

void TC3_Handler() 
{
  TcCount16* TC = (TcCount16*) TC3;
  // If this interrupt is due to the compare register matching the timer count
  // we toggle the LED.
  if (TC->INTFLAG.bit.MC0 == 1) {
    TC->INTFLAG.bit.MC0 = 1;
    
    //  collect_imu_data();

  }
}

void imu_setup(){
  dev_i2c.begin();
  
  // Initialize I2C bus.
  LSM6DSOSensor AccGyr(&dev_i2c);
  AccGyr.begin();

  AccGyr.Set_X_ODR(416); // Acc 416Hz
  AccGyr.Set_X_FS(4); // Acc range: 4g  
  AccGyr.Set_G_ODR(416); // Gyro 416Hz
  AccGyr.Set_G_FS(500); // Gyro range: 500 dps
  AccGyr.Enable_X(); 
  AccGyr.Enable_G();
}

//Utility functions

float getVoltage()
{
  
  float measuredvbat = analogRead(VBATPIN);
  measuredvbat *= 2;    // we divided by 2, so multiply back
  measuredvbat *= 3.3;  // Multiply by 3.3V, our reference voltage
  measuredvbat /= 1024; // convert to voltage
  return measuredvbat;
}

// void send_beacon(uint8_t dst, uint16_t seq_no, uint16_t ack_no){
// 	beacon_msg[MSG_TYPE_IDX] = BEACON_TYPE;
// 	beacon_msg[SRC_IDX] = my_index;
// 	beacon_msg[DST_IDX] = dst;
// 	beacon_msg[SEQ_IDX] = ((seq_no) & 0xFF);
// 	beacon_msg[SEQ_IDX + 1] = ((seq_no >> 8) & 0xFF);
// 	beacon_msg[ACK_IDX] = ((ack_no) & 0xFF);
// 	beacon_msg[ACK_IDX + 1] = ((ack_no >> 8) & 0xFF);
// 	prev_send_seq[dst] = seq_no;

// 	// Set prevRecvTime field in packet.
// 	set_timestamp_to_packet_u64(&beacon_msg[PREV_RX_TS_IDX], prev_my_recv_time[dst]);

//   // Set prevSendTime field in packet.
//   DW1000.newTransmit();
//   DW1000Time txTime;
//   DW1000Time deltaTime = DW1000Time(FIXED_DELAY, DW1000Time::MICROSECONDS);
//   txTime = DW1000.setDelay(deltaTime);
//   prev_my_send_time[dst]= txTime.getTimestamp();
// 	set_timestamp_to_packet_u64(&beacon_msg[CURRENT_TX_TS_IDX], prev_my_send_time[dst]);
// 	generic_send(beacon_msg, sizeof(beacon_msg));

//   while(!sendComplete);
//   sendComplete = false;
// }



#ifdef __arm__
// should use uinstd.h to define sbrk but Due causes a conflict
extern "C" char* sbrk(int incr);
#else  // __ARM__
extern char *__brkval;
#endif  // __arm__



int freeMemory() {
  char top;
#ifdef __arm__
  return &top - reinterpret_cast<char*>(sbrk(0));
#elif defined(CORE_TEENSY) || (ARDUINO > 103 && ARDUINO != 151)
  return &top - __brkval;
#else  // __arm__
  return __brkval ? &top - __brkval : &top - __malloc_heap_start;
#endif  // __arm__
}

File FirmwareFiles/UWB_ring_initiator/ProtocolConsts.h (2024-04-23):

#ifndef PROTOCOL_CONSTS_H
#define PROTOCOL_CONSTS_H

typedef uint8_t uint8;
typedef uint16_t uint16;
typedef uint32_t uint32;
typedef int8_t int8;
typedef int16_t int16;
typedef int32_t int32;

#define BROADCAST_ID 0xFF

/* Return code */
#define NO_ERROR 0x00
#define ERROR_GENERAL 0x01
#define ERROR_INVALID_DISTANCE 0x02
#define RET_INSUFFICIENT_DISTANCE_MEASUREMENTS 0x10
#define RET_PROXIMITY_CHECK_FAIL 0x11
#define RET_PROXIMITY_CHECK_SUCCESS 0x12

/* Define the format of the packet. */
/* Handshaking request. */
#define MSG_TYPE_IDX 0
#define SRC_IDX 1
#define DST_IDX 2
#define SEQ_IDX 3
#define ACK_IDX 5

/* Handshaking reply + handshaking PCACK. */
#define SESSION_KEY_IDX 7

/* Handshaking RINGACK. */
#define HS_RINGACK_STATUS_IDX 7

/* Pattern info*/
#define PAT_N_ALL_IMU_COUNT_IDX 7
#define PAT_FROM_IMU_IDX 9
#define PAT_TO_IMU_IDX 11
#define PAT_INFO_COMPLETE_BIT_IDX 13
#define PAT_N_IMU_IDX 14
#define PAT_IMU_MEASUREMENTS_IDX 15


#define PREV_RX_TS_IDX 7
#define CURRENT_TX_TS_IDX 12
#define RESERVED_MASK_IDX 17

#define SKETCH_N_IMU_IDX 48


/* Length of each type of message. */
#define SHORT_MSG_LEN 2
#define IMU_MSG_LEN 4
#define ACC_MSG_LEN 4
#define GYRO_MSG_LEN 4
#define IMU_TIME_MSG_LEN 4 
#define BEACON_MSG_LEN 512
#define TS_LEN 5
#define SESSION_KEY_LEN 32

#define RESP_DURATION 2000

/* Message types.*/
#define BEACON_TYPE 0x01
#define HS_REQUEST_TYPE 0x02
#define HS_REPLY_TYPE 0x03
#define HS_PCACK_TYPE 0x04
#define HS_RINGACK_TYPE 0x05
#define TWR_BEACON_TYPE 0x06
#define PAT_REQUEST_TYPE 0x07
#define PAT_REPLY_TYPE 0x08
#define PAT_SHORTBEACON_TYPE 0x09
#define PAT_INFO_START_TYPE 0x0A
#define PAT_INFO_ACK_TYPE 0x0B
#define PAT_INFO_TYPE 0x0C
#define PAT_INFO_IMU_ACK_TYPE 0x0D

/*Output message types. */
#define OUTPUT_TWR_CIR_TYPE 0x01
#define OUTPUT_TWR_ONLY_TYPE 0x02
#define OUTPUT_CIR_VERIFIER_TYPE 0x03
#define OUTPUT_IMU_ONLY_TYPE 0x04
#define OUTPUT_TWR_IMU_TYPE 0x05

/* Return code */
#define NO_ERROR 0x00
#define ERROR_GENERAL 0x01
#define ERROR_INVALID_DISTANCE 0x02
#define RET_INSUFFICIENT_DISTANCE_MEASUREMENTS 0x10
#define RET_PROXIMITY_CHECK_FAIL 0x11
#define RET_PROXIMITY_CHECK_SUCCESS 0x12
#define RET_IMU_INFO_COMPLETE 0x13
#define RET_IMU_INFO_NOTCOMPLETE 0x14
#define RET_RECEIVE_IMU_ACK 0x15
#define RET_RECEIVE_WRONG_ACK 0x16


#define MAX_POLL_LEN 12
#define MAX_RESP_LEN 8
#define MAX_FINAL_LEN 44
#define MAX_REPORT_LEN 10
// (56 if imu not included)
#define PROBE_LEN 125//125    //4 byte info + 5 byte transmission time + 6*TRXNUM + (5,8,10)*9*2 [IMU] + 2

typedef enum {STATE_IDLE, STATE_SEND, STATE_RECEIVE,
	/*Login device, handshaking. */
	STATE_HS_SEND_REQUEST, STATE_HS_REPLY_EXPECTED, STATE_HS_SEND_PCACK, STATE_HS_RINGACK_EXPECTED,
	/*Ring, handshaking. */
	STATE_HS_REQUEST_EXPECTED, STATE_HS_SEND_REPLY, STATE_HS_PCACK_EXPECTED, STATE_HS_SEND_RINGACK,
    /*Ring/Login device, two way ranging. */
    STATE_TWR_SEND, STATE_TWR_RECEIVE,
    /*Login device, pattern recognition*/
	STATE_PAT_SEND_REQUEST, STATE_PAT_REPLY_EXPECTED, STATE_PAT_SEND_SHORTBEACON,
	STATE_PAT_INFO_EXPECTED,
    /*Ring, pattern recognition*/
    STATE_PAT_SEND_REPLY, STATE_PAT_SHORTBEACON_EXPECTED, STATE_PAT_SEND_INFO_START,
    STATE_PAT_INFO_ACK_EXPECTED, STATE_PAT_SEND_INFO, STATE_PAT_INFO_IMU_ACK_EXPECTED,
    STATE_ALL_COMPLETE
} STATES;

typedef enum send_modes{SEND_IMMEDIATE, SEND_DELAY_FIXED, SEND_DELAY_BOARDID, SEND_SHORT_DELAY_BOARDID, SEND_LONG_DELAY_BOARDID, SEND_DELAY_GIVEN} SEND_MODES;


#define DEBUG_FLAG 0
#define TIME_UNIT 1/128/499.2e6

#define OUR_UWB_FEATHER 1
#define AUS_UWB_FEATHER 0


#define YIFENG_TEST 0


/* Configurations */
#define FIXED_DELAY 6000
#define WAIT_BEFORE_POLL 2
#define TEN_SECOND_TIMEOUT_US 10e6
#define FIVE_SECOND_TIMEOUT_US 5e6
#define ONE_SECOND_TIMEOUT_US 1e6
#define STANDARD_TIMEOUT_US 60000
#define ONE_MSEC 0x3CF00
#define MAX_SEQ_NUMBER 65535
#define IMU_BUFFER_SIZE 100
#define MAX_IMU_EACH_PACKET_TWR_LOGIC 16
#define MAX_IMU_EACH_PACKET_TYPICAL 19
#define MAX_IMU_SAMPLES 100
#define MAX_CIR_VERIFIER 3

#define MAX_IMU_SAMPLES_IN_BUFFER_TWRCIR 16
#define MAX_IMU_SAMPLES_IN_BUFFER_APP MAX_IMU_SAMPLES

const uint16_t deca_timeout_us = 40000;
const int response_expect_timeout_us = 60000;
const int my_index = 1;
const int imu_rate = 100;
const byte my_session_key[32] = {
    1, 2, 3, 4, 5, 6, 7, 8, 9, 10, 11, 12, 13, 14, 15, 16,
    17, 18, 19, 20, 21, 22, 23, 24, 25, 26, 27, 28, 29, 30, 31, 32
};


#endif

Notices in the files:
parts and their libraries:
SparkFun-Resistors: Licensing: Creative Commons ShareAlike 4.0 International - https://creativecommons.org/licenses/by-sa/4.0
